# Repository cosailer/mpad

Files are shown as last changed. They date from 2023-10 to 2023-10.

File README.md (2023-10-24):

# mpad
**>> info**\
a 12 key macropad designed with atmega32u4, compatible with QMK, which is built with **virtser** and **I2C** enabled. the virtual serial port is used to control the 12 onboard backlight led, the I2C bus has a gesture sensor APDS-9960 connected to detect hand movement direction(up/down/left/right/near/far), proximity and light intensity. there is also a mouse encoder mounted.

**>> files**\
**mpad** :KiCad design files\
**qmk_firmware\keyboards\mpad** : firmware source for qmk build system\
**mpad.py** : a python test script to control the backlight LED via serial port\
**register_dump.txt** : an example register dump for APDS-9960

**>> setup**\
1, pin assignment, left: key and matrix assignment, right: backlight pin assignment
```
        D5     D4     D6       0,F5
     ┌──────┬──────┬──────┐
  B4 │ ESC  │ CALC │ MYCM │    1,B2   2,B1   3,B0
     ├──────┼──────┼──────┤
  B5 │ Ctl+C│ DEL  │ BSPC │    4,B3   5,F6   6,E6
     ├──────┼──────┼──────┤
  B6 │ SPACE│  Up  │  ENT │    7,F7   8,D7   9,F4
     ├──────┼──────┼──────┤
  B7 │ Left │ Down │ Right│   10,C6  11,C7  12,E2
     └──────┴──────┴──────┘
```

2, the onboard gesture sensor APDS-9960 is installed horizontally, the down movement is mapped to left key, up => right key, left => up key, right => down key

3, the 12 key individual backlight(single color) can be controlled from PC or mcu directly, allows it to be a LED notification light

the communication protocol: (each [xx] corresponds to 1 byte)
```
cmd 1: [0xAA] [ B1 ] [ B2 ] [0xE1] : set back light   ACK 1:[0xE1] ['\n']
cmd 2: [0xAA] [0xE2] : request timer                  ACK 2:[0xE2] [ T1 ] [ T2 ] [ T3 ] [ T4 ] ['\n']
cmd 3: [0xAA] [0xE3] : request voltage                ACK 3:[0xE3] [ U1 ] [ U2 ] ['\n']
cmd 4: [0xAA] [0xE4] : request die_temp               ACK 4:[0xE4] [ D1 ] [ D2 ] ['\n']
cmd 5: [0xAA] [0xE5] : request proximity              ACK 5:[0xE5] [ P1 ] ['\n']
cmd 6: [0xAA] [0xE6] : request light                  ACK 6:[0xE6] [ L1 ] [ L2 ] ['\n']
```
the script **mpad.py** sends commands to mpad every 100ms, to control the backlight LED and request some other system information. 

4, an onboard mouse encoder is mapped to volume control, which can be controlled via one finger

**>> PCB**\
the PCB is designed with KiCad 7.07. with the addition of an encoder, the PCB height size has grown over the 100mm. a small daughter board is attached to mount the gesture sensor and the encoder, the daughter board also has some extra room to mount other I2C sensors.

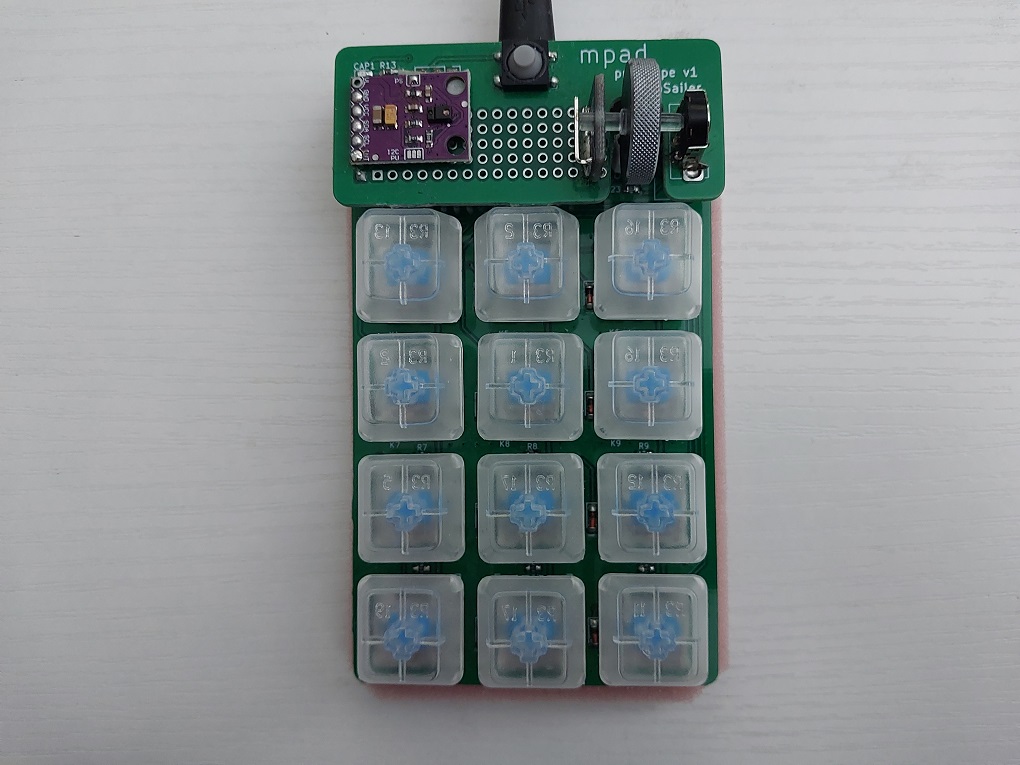
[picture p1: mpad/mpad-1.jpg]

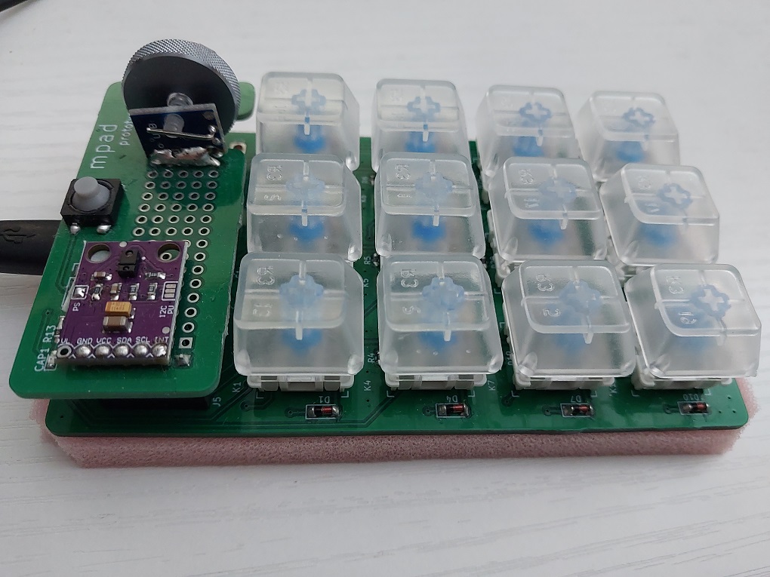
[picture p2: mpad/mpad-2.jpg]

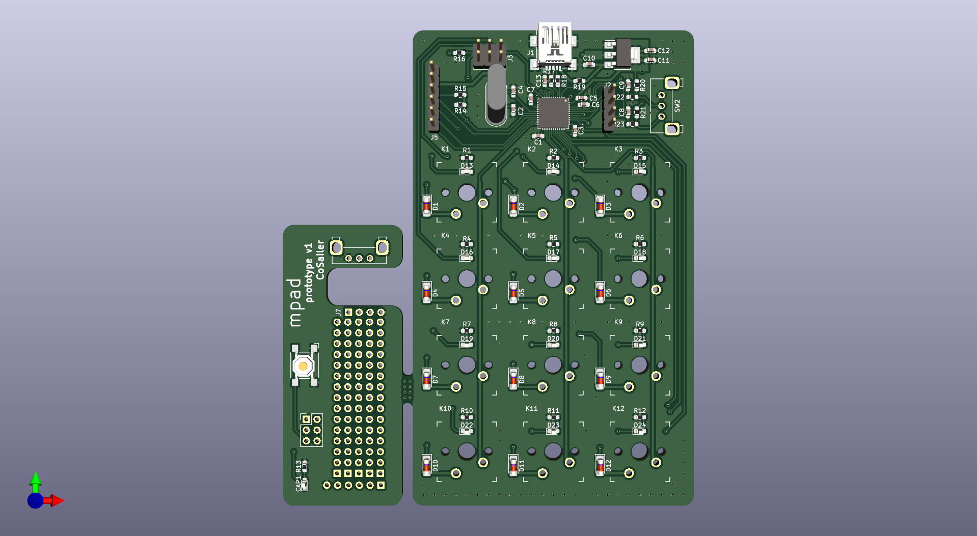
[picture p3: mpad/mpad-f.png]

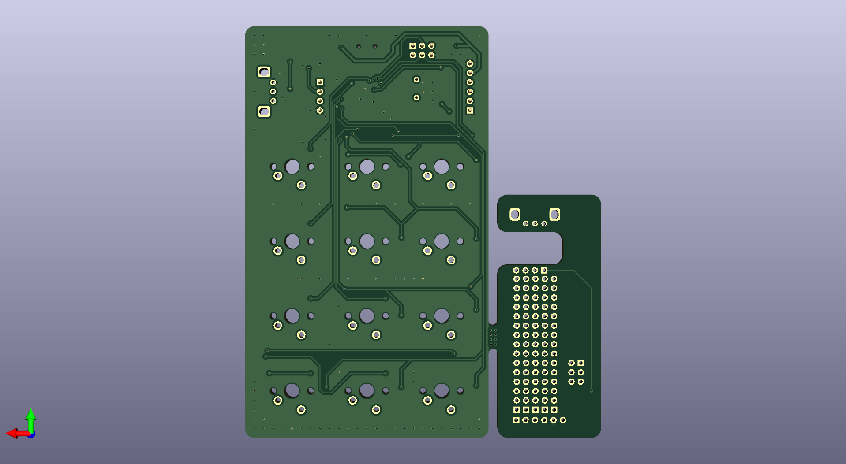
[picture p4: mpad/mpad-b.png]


**>> notes**\
1, even with interrupt enabled, the driver for the APDS-9960 still needs hundreds of milliseconds to measure/calculate the direction of the movements, during this time the keypad will not respond to other inputs, this is the limitation of the sensor.

2, apart from normal movement direction detection, another gesture is also possible: **proximity tap** within a predfined time window (e.g. 1.5 seconds), it could be one tap, two taps or more taps. but proximity tap cannot be enabled togethe with the normal gesture detection.

3, the APDS-9960 interrupt is active low.

4, the serial port in qmk running on atmega32u4 can only process the received data one byte a time, so that it does not block normal keyboard functions.

**>> refernces**\
1, https://qmk.fm \
2, https://github.com/njeff/cherryblossom \
3, https://www.broadcom.com/products/optical-sensors/integrated-ambient-light-and-proximity-sensors/apds-9960 \
4, https://learn.sparkfun.com/tutorials/apds-9960-rgb-and-gesture-sensor-hookup-guide/all

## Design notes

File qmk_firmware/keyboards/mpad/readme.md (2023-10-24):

# mpad

mpad

*A short description of the keyboard/project*

* Keyboard Maintainer: [CoSailer](https://github.com/CoSailer)
* Hardware Supported: *The PCBs, controllers supported*
* Hardware Availability: *Links to where you can find this hardware*

Make example for this keyboard (after setting up your build environment):

    make mpad:default

Flashing example for this keyboard:

    make mpad:default:flash

See the [build environment setup](https://docs.qmk.fm/#/getting_started_build_tools) and the [make instructions](https://docs.qmk.fm/#/getting_started_make_guide) for more information. Brand new to QMK? Start with our [Complete Newbs Guide](https://docs.qmk.fm/#/newbs).

## Bootloader

Enter the bootloader in 3 ways:

* **Bootmagic reset**: Hold down the key at (0,0) in the matrix (usually the top left key or Escape) and plug in the keyboard
* **Physical reset button**: Briefly press the button on the back of the PCB - some may have pads you must short instead
* **Keycode in layout**: Press the key mapped to `RESET` if it is available

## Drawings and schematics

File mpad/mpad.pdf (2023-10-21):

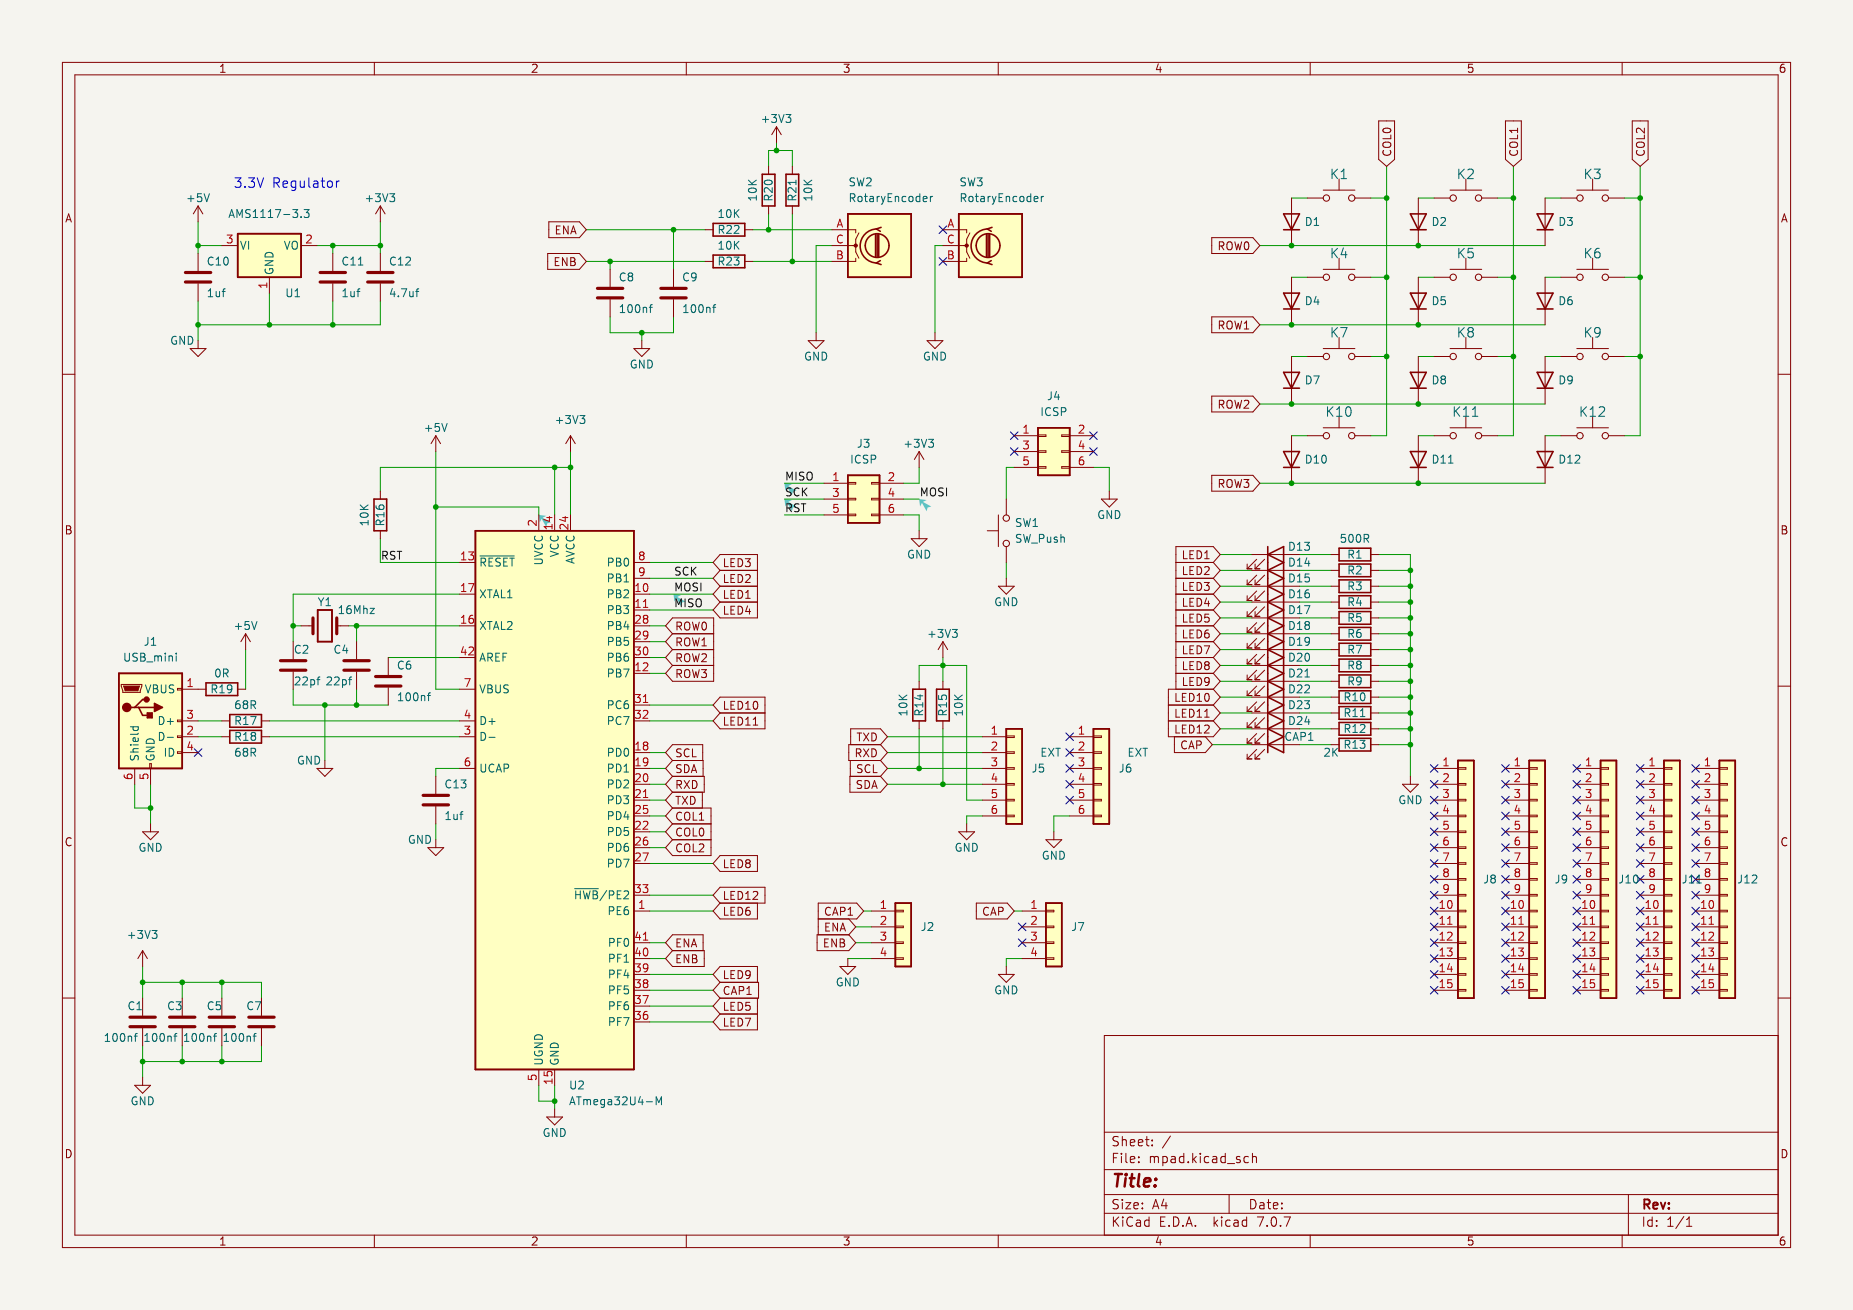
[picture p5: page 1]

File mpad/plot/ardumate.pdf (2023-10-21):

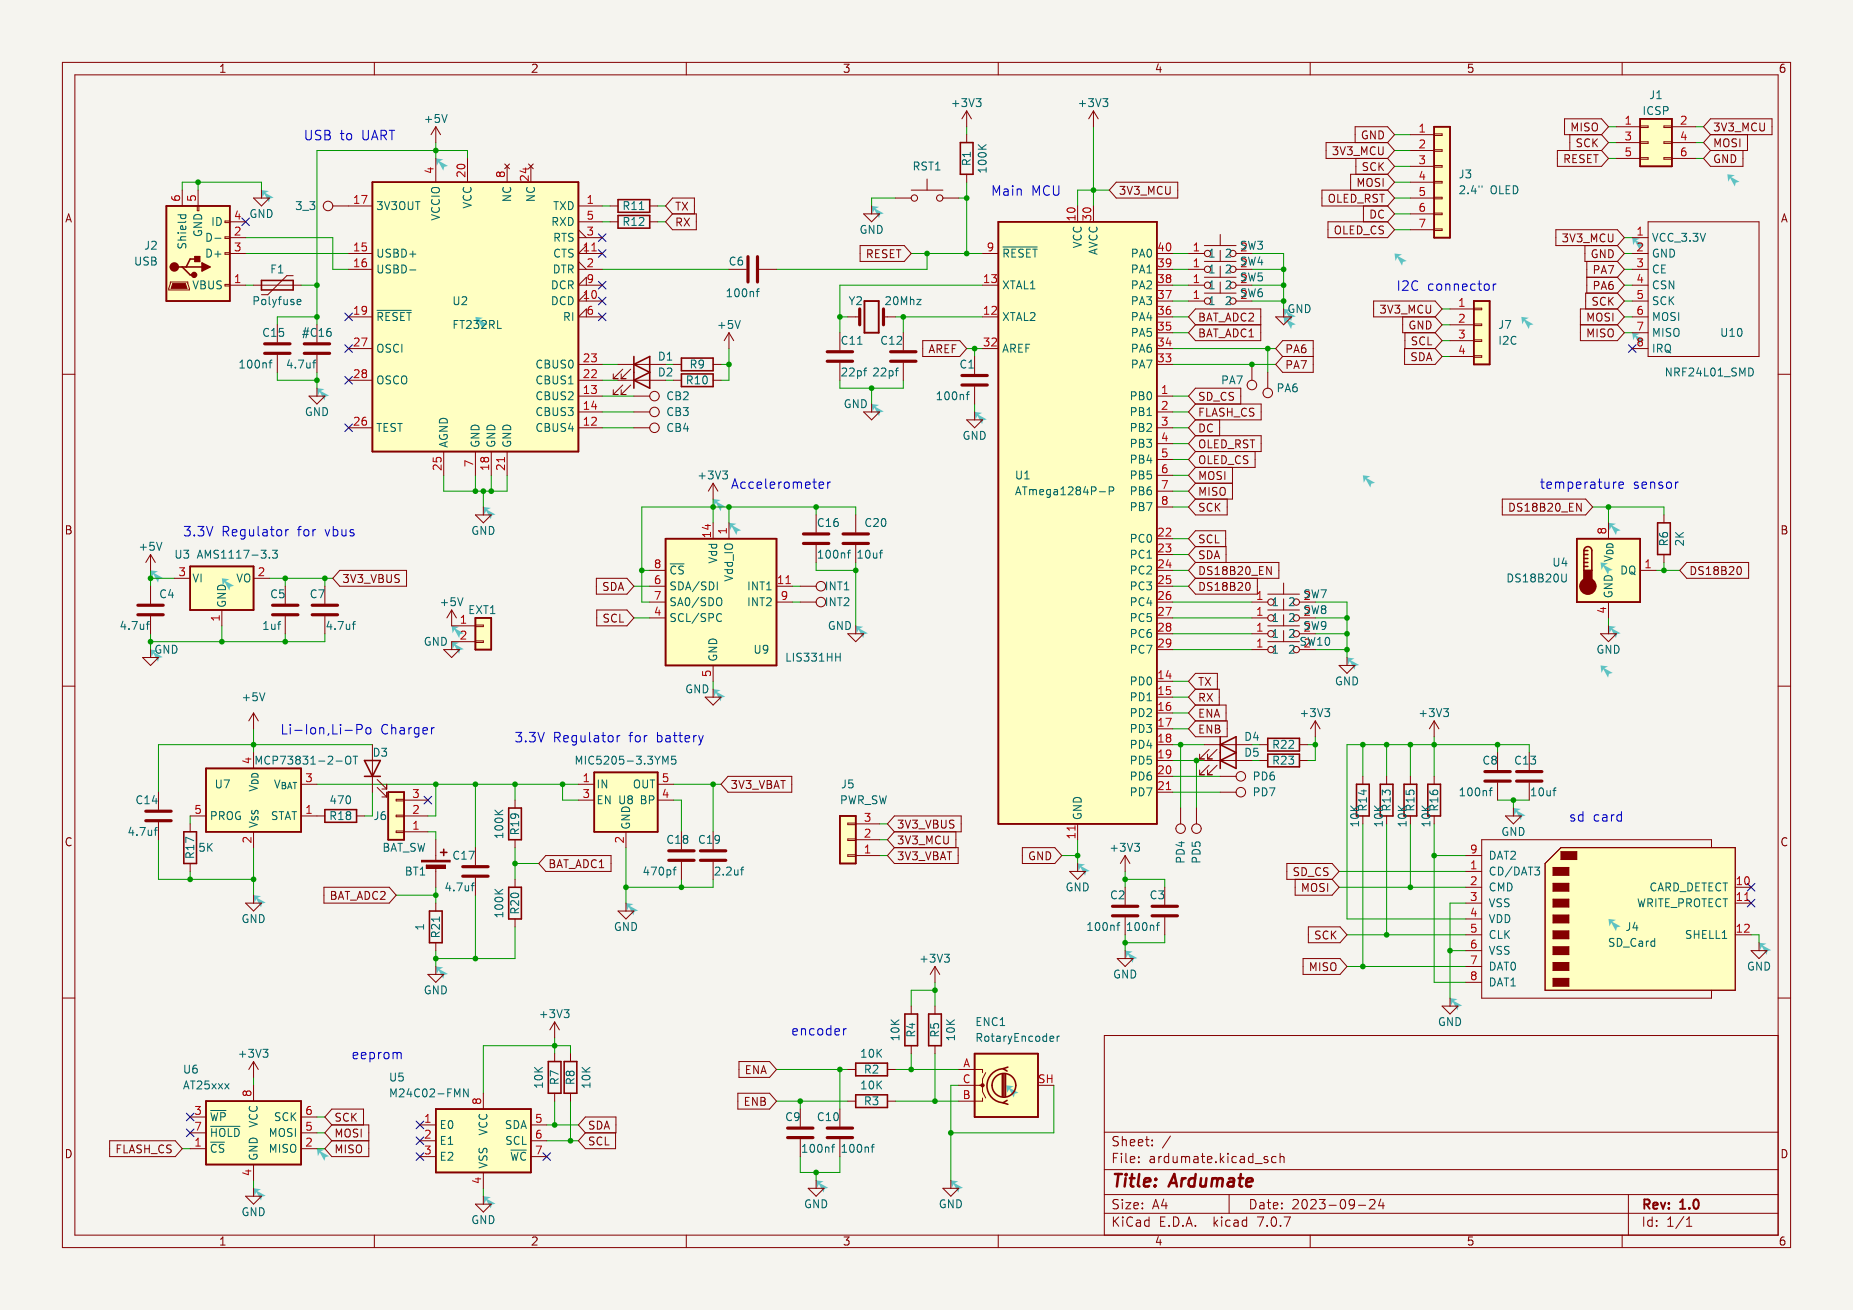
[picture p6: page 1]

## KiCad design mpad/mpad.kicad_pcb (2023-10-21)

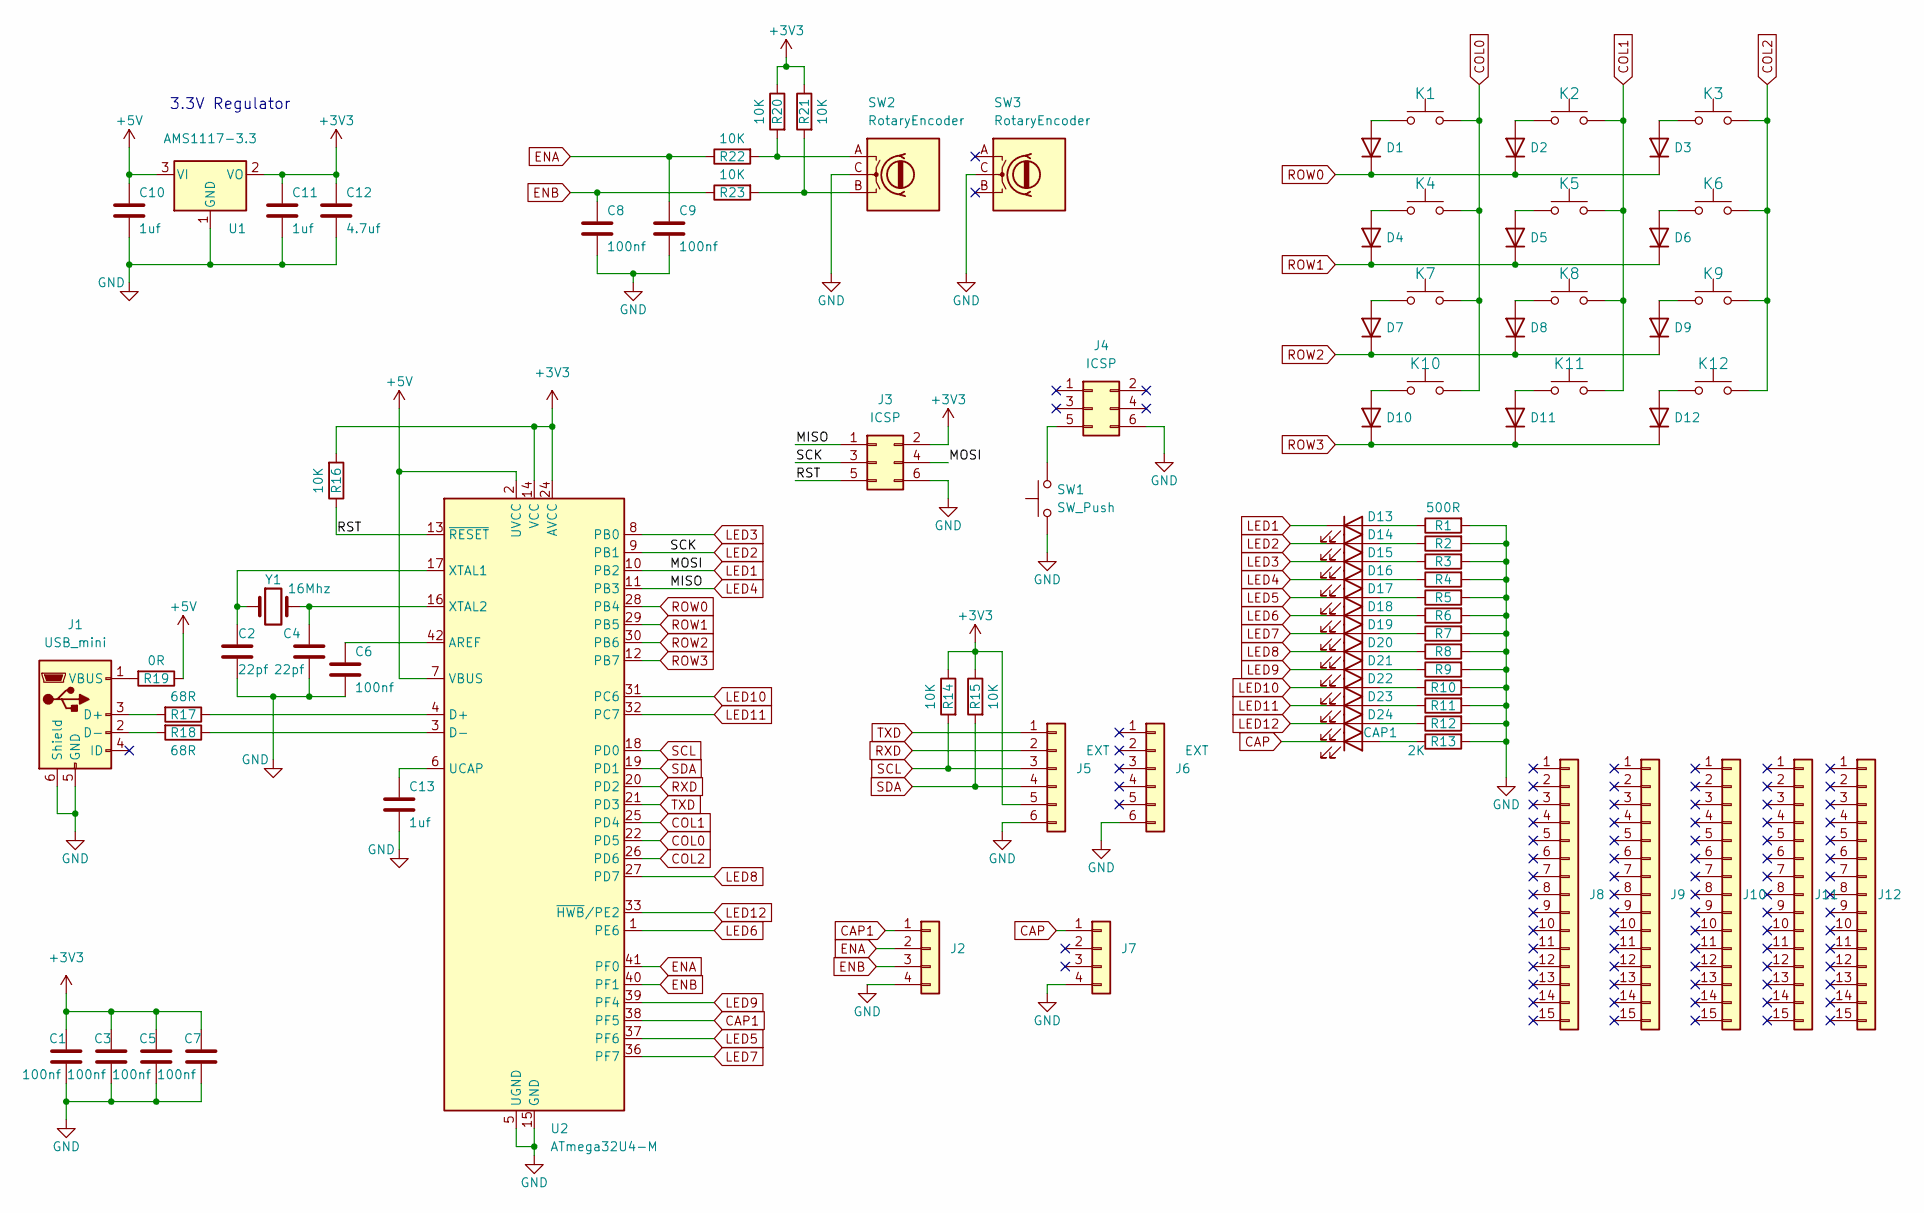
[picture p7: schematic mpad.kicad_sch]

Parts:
C1, C3, C5, C6, C7, C8, C9: 100nf; C_0603_1608Metric_Pad1.08x0.95mm_HandSolder
C2, C4: 22pf; C_0603_1608Metric_Pad1.08x0.95mm_HandSolder
C10, C11, C13: 1uf; C_0603_1608Metric_Pad1.08x0.95mm_HandSolder
C12: 4.7uf; C_0603_1608Metric_Pad1.08x0.95mm_HandSolder
CAP1: LED; LED_0603_1608Metric_Pad1.05x0.95mm_HandSolder
D1, D2, D3, D4, D5, D6, D7, D8, D9, D10, D11, D12: D; D_MiniMELF
D13, D14, D15, D16, D17, D18, D19, D20, D21, D22, D23, D24: LED; LED_0603_1608Metric_Pad1.05x0.95mm_HandSolder
J1: USB_mini; USB_Mini-B_Wuerth_65100516121_Horizontal
J2, J7: Status; PinHeader_1x04_P2.54mm_Vertical
J3, J4: ICSP; PinHeader_2x03_P2.54mm_Vertical
J5, J6: EXT; PinHeader_1x06_P2.54mm_Vertical
J8, J9, J10, J11, J12: UART; PinHeader_1x15_P2.54mm_Vertical
K1, K2, K3, K4, K5, K6, K7, K8, K9, K10, K11, K12: KEYSW; SW_MX
R1, R2, R3, R4, R5, R6, R7, R8, R9, R10, R11, R12: 500R; R_0603_1608Metric_Pad0.98x0.95mm_HandSolder
R13: 2K; R_0603_1608Metric_Pad0.98x0.95mm_HandSolder
R14, R15, R16, R20, R21, R22, R23: 10K; R_0603_1608Metric_Pad0.98x0.95mm_HandSolder
R17, R18: 68R; R_0603_1608Metric_Pad0.98x0.95mm_HandSolder
R19: 0R; R_0603_1608Metric_Pad0.98x0.95mm_HandSolder
SW1: SW_Push; SW_SPST_Omron_B3FS-100xP
SW2, SW3: RotaryEncoder; RotaryEncoder_Bourns_Horizontal_PEC12R-2xxxF-Nxxxx
U1: AMS1117-3.3; SOT-223-3_TabPin2
U2: ATmega32U4-M; QFN-44-1EP_7x7mm_P0.5mm_EP5.15x5.15mm_no_pad
Y1: 16Mhz; Crystal_HC18-U_Vertical

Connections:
+3V3: C1.1, C3.1, C5.1, C7.1, C11.1, C12.1, J3.2, J5.5, R14.1, R15.1, R16.2, R20.1, R21.1, U1.2 (VO), U2.14 (VCC), U2.24 (AVCC), U2.34 (VCC), U2.44 (AVCC)
+5V: C10.1, R19.1, U1.3 (VI), U2.2 (UVCC), U2.7 (VBUS)
/RST: J3.5, R16.1, U2.13 (~RESET)
CAP: CAP1.1 (K), J7.1
CAP1: J2.1, U2.38 (PF5)
COL0: K1.2, K4.2, K7.2, K10.2, U2.22 (PD5)
COL1: K2.2, K5.2, K8.2, K11.2, U2.25 (PD4)
COL2: K3.2, K6.2, K9.2, K12.2, U2.26 (PD6)
ENA: C9.1, J2.2, R22.1, U2.41 (PF0)
ENB: C8.1, J2.3, R23.1, U2.40 (PF1)
GND: C1.2, C2.2, C3.2, C4.2, C5.2, C6.2, C7.2, C8.2, C9.2, C10.2, C11.2, C12.2, C13.2, J1.5 (GND), J1.6 (Shield), J2.4, J3.6, J4.6, J5.6, J6.6, J7.4, R1.2, R2.2, R3.2, R4.2, R5.2, R6.2, R7.2, R8.2, R9.2, R10.2, R11.2, R12.2, R13.2, SW1.1, SW2.C, SW3.C, U1.1 (GND), U2.5 (UGND), U2.15 (GND), U2.23 (GND), U2.35 (GND), U2.43 (GND)
LED1: D13.1 (K), J3.4, U2.10 (PB2)
LED2: D14.1 (K), J3.3, U2.9 (PB1)
LED3: D15.1 (K), U2.8 (PB0)
LED4: D16.1 (K), J3.1, U2.11 (PB3)
LED5: D17.1 (K), U2.37 (PF6)
LED6: D18.1 (K), U2.1 (PE6)
LED7: D19.1 (K), U2.36 (PF7)
LED8: D20.1 (K), U2.27 (PD7)
LED9: D21.1 (K), U2.39 (PF4)
LED10: D22.1 (K), U2.31 (PC6)
LED11: D23.1 (K), U2.32 (PC7)
LED12: D24.1 (K), U2.33 (~HWB/PE2)
unnamed: CAP1.2 (A), R13.1
unnamed: D1.2 (A), K1.1
unnamed: D2.2 (A), K2.1
unnamed: D3.2 (A), K3.1
unnamed: D4.2 (A), K4.1
unnamed: D5.2 (A), K5.1
unnamed: D6.2 (A), K6.1
unnamed: D7.2 (A), K7.1
unnamed: D8.2 (A), K8.1
unnamed: D9.2 (A), K9.1
unnamed: D10.2 (A), K10.1
unnamed: D11.2 (A), K11.1
unnamed: D12.2 (A), K12.1
unnamed: D13.2 (A), R1.1
unnamed: D14.2 (A), R2.1
unnamed: D15.2 (A), R3.1
unnamed: D16.2 (A), R4.1
unnamed: D17.2 (A), R5.1
unnamed: D18.2 (A), R6.1
unnamed: D19.2 (A), R7.1
unnamed: D20.2 (A), R8.1
unnamed: D21.2 (A), R9.1
unnamed: D22.2 (A), R10.1
unnamed: D23.2 (A), R11.1
unnamed: D24.2 (A), R12.1
unnamed: J1.3 (D+), R17.2
unnamed: J1.2 (D-), R18.2
unnamed: J1.1 (VBUS), R19.2
unnamed: J4.5, SW1.2
unnamed: R20.2, R22.2, SW2.A
unnamed: R21.2, R23.2, SW2.B
unnamed: C6.1, U2.42 (AREF)
unnamed: R17.1, U2.4 (D+)
unnamed: R18.1, U2.3 (D-)
unnamed: C13.1, U2.6 (UCAP)
unnamed: C2.1, U2.17 (XTAL1), Y1.1
unnamed: C4.1, U2.16 (XTAL2), Y1.2
ROW0: D1.1 (K), D2.1 (K), D3.1 (K), U2.28 (PB4)
ROW1: D4.1 (K), D5.1 (K), D6.1 (K), U2.29 (PB5)
ROW2: D7.1 (K), D8.1 (K), D9.1 (K), U2.30 (PB6)
ROW3: D10.1 (K), D11.1 (K), D12.1 (K), U2.12 (PB7)
RXD: J5.2, U2.20 (PD2)
SCL: J5.3, R14.2, U2.18 (PD0)
SDA: J5.4, R15.2, U2.19 (PD1)
TXD: J5.1, U2.21 (PD3)

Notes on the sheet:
3.3V Regulator

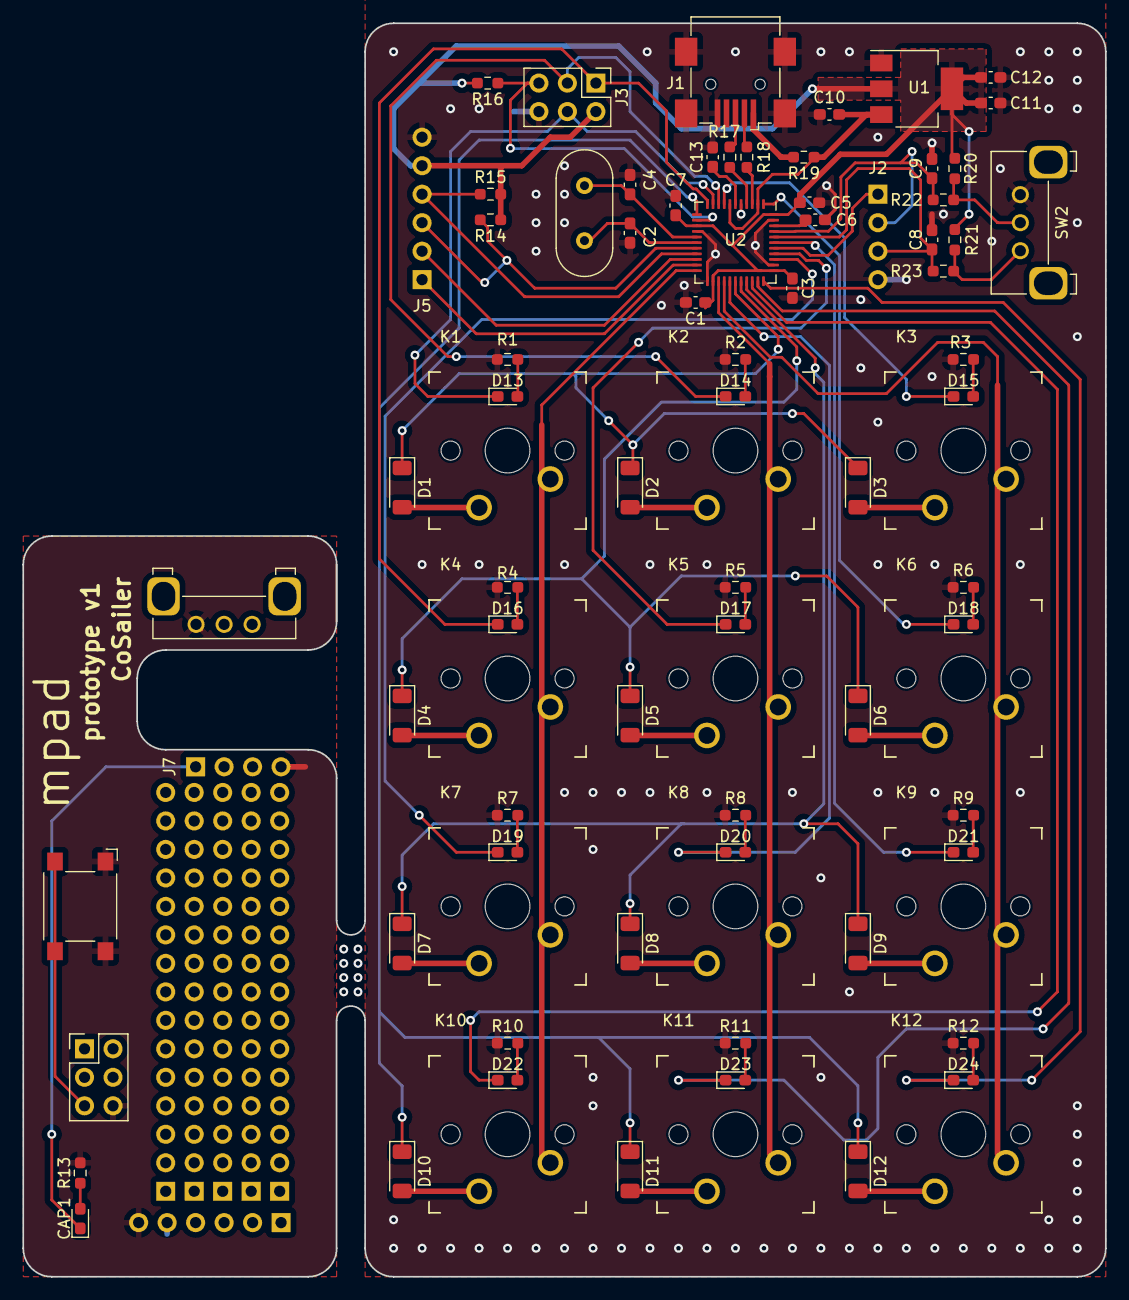
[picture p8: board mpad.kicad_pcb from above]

Board: 2 copper layers, 96.5 x 111.8 mm, 91 parts (0 on the bottom side), 68 nets.

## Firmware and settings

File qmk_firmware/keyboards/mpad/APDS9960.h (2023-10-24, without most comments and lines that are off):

#include "stdint.h"
#define SparkFun_APDS9960_H
#define TIMEOUT                 5
#define APDS9960_I2C_ADDR       (0x39 << 1)
#define GESTURE_THRESHOLD_OUT   10
#define GESTURE_SENSITIVITY_1   50
#define GESTURE_SENSITIVITY_2   20
#define ERROR                   0xFF
#define APDS9960_ID_1           0xAB
#define APDS9960_ID_2           0x9C
#define FIFO_PAUSE_TIME         30      // Wait period (ms) between FIFO reads
#define APDS9960_ENABLE         0x80
#define APDS9960_ATIME          0x81
#define APDS9960_WTIME          0x83
#define APDS9960_AILTL          0x84
#define APDS9960_AILTH          0x85
#define APDS9960_AIHTL          0x86
#define APDS9960_AIHTH          0x87
#define APDS9960_PILT           0x89
#define APDS9960_PIHT           0x8B
#define APDS9960_PERS           0x8C
#define APDS9960_CONFIG1        0x8D
#define APDS9960_PPULSE         0x8E
#define APDS9960_CONTROL        0x8F
#define APDS9960_CONFIG2        0x90
#define APDS9960_ID             0x92
#define APDS9960_STATUS         0x93
#define APDS9960_CDATAL         0x94
#define APDS9960_CDATAH         0x95
#define APDS9960_RDATAL         0x96
#define APDS9960_RDATAH         0x97
#define APDS9960_GDATAL         0x98
#define APDS9960_GDATAH         0x99
#define APDS9960_BDATAL         0x9A
#define APDS9960_BDATAH         0x9B
#define APDS9960_PDATA          0x9C
#define APDS9960_POFFSET_UR     0x9D
#define APDS9960_POFFSET_DL     0x9E
#define APDS9960_CONFIG3        0x9F
#define APDS9960_GPENTH         0xA0
#define APDS9960_GEXTH          0xA1
#define APDS9960_GCONF1         0xA2
#define APDS9960_GCONF2         0xA3
#define APDS9960_GOFFSET_U      0xA4
#define APDS9960_GOFFSET_D      0xA5
#define APDS9960_GOFFSET_L      0xA7
#define APDS9960_GOFFSET_R      0xA9
#define APDS9960_GPULSE         0xA6
#define APDS9960_GCONF3         0xAA
#define APDS9960_GCONF4         0xAB
#define APDS9960_GFLVL          0xAE
#define APDS9960_GSTATUS        0xAF
#define APDS9960_IFORCE         0xE4
#define APDS9960_PICLEAR        0xE5
#define APDS9960_CICLEAR        0xE6
#define APDS9960_AICLEAR        0xE7
#define APDS9960_GFIFO_U        0xFC
#define APDS9960_GFIFO_D        0xFD
#define APDS9960_GFIFO_L        0xFE
#define APDS9960_GFIFO_R        0xFF
#define APDS9960_PON            0b00000001
#define APDS9960_AEN            0b00000010
#define APDS9960_PEN            0b00000100
#define APDS9960_WEN            0b00001000
#define APSD9960_AIEN           0b00010000
#define APDS9960_PIEN           0b00100000
#define APDS9960_GEN            0b01000000
#define APDS9960_GVALID         0b00000001
#define SET_MODE_OFF            0
#define SET_MODE_ON             1
#define POWER                   0
#define AMBIENT_LIGHT           1
#define PROXIMITY               2
#define SET_MODE_WAIT           3
#define AMBIENT_LIGHT_INT       4
#define PROXIMITY_INT           5
#define GESTURE                 6
#define ALL                     7
#define LED_DRIVE_100MA         0
#define LED_DRIVE_50MA          1
#define LED_DRIVE_25MA          2
#define LED_DRIVE_12_5MA        3
#define PGAIN_1X                0
#define PGAIN_2X                1
#define PGAIN_4X                2
#define PGAIN_8X                3
#define AGAIN_1X                0
#define AGAIN_4X                1
#define AGAIN_16X               2
#define AGAIN_64X               3
#define GGAIN_1X                0
#define GGAIN_2X                1
#define GGAIN_4X                2
#define GGAIN_8X                3
#define LED_BOOST_100           0
#define LED_BOOST_150           1
#define LED_BOOST_200           2
#define LED_BOOST_300           3
#define GWTIME_0MS              0
#define GWTIME_2_8MS            1
#define GWTIME_5_6MS            2
#define GWTIME_8_4MS            3
#define GWTIME_14_0MS           4
#define GWTIME_22_4MS           5
#define GWTIME_30_8MS           6
#define GWTIME_39_2MS           7
#define DEFAULT_ATIME           219     // 103ms
#define DEFAULT_WTIME           246     // 27ms
#define DEFAULT_PROX_PPULSE     0x87    // 16us, 8 pulses
#define DEFAULT_GESTURE_PPULSE  0x89    // 16us, 10 pulses
#define DEFAULT_POFFSET_UR      0       // 0 offset
#define DEFAULT_POFFSET_DL      0       // 0 offset
#define DEFAULT_CONFIG1         0x60    // No 12x wait (WTIME) factor
#define DEFAULT_LDRIVE          LED_DRIVE_100MA
#define DEFAULT_PGAIN           PGAIN_1X
#define DEFAULT_AGAIN           AGAIN_1X
#define DEFAULT_PILT            0       // Low proximity threshold
#define DEFAULT_PIHT            50      // High proximity threshold
#define DEFAULT_AILT            0xFFFF  // Force interrupt for calibration
#define DEFAULT_AIHT            0
#define DEFAULT_PERS            0x11    // 2 consecutive prox or ALS for int.
#define DEFAULT_CONFIG2         0x01    // No saturation interrupts or LED boost
#define DEFAULT_CONFIG3         0       // Enable all photodiodes, no SAI
#define DEFAULT_GPENTH          30      // Threshold for entering gesture mode
#define DEFAULT_GEXTH           15      // Threshold for exiting gesture mode
#define DEFAULT_GCONF1          0x40    // 4 gesture events for int., 1 for exit
#define DEFAULT_GGAIN           GGAIN_1X //GGAIN_1X
#define DEFAULT_GLDRIVE         LED_DRIVE_100MA
#define DEFAULT_GWTIME          GWTIME_2_8MS
#define DEFAULT_GOFFSET         0       // No offset scaling for gesture mode
#define DEFAULT_GPULSE          0xC9    // 32us, 10 pulses
#define DEFAULT_GCONF3          0       // All photodiodes active during gesture
#define DEFAULT_GIEN            0       // Disable gesture interrupts
enum {
  DIR_NONE,
  DIR_LEFT,
  DIR_RIGHT,
  DIR_UP,
  DIR_DOWN,
  DIR_NEAR,
  DIR_FAR,
  DIR_ALL
};
enum {
  NA_STATE,
  NEAR_STATE,
  FAR_STATE,
  ALL_STATE
};
typedef struct gesture_data_type {
    uint8_t u_data[32];
    uint8_t d_data[32];
    uint8_t l_data[32];
    uint8_t r_data[32];
    uint8_t index;
    uint8_t total_gestures;
    uint8_t in_threshold;
    uint8_t out_threshold;
} gesture_data_type;
uint8_t apds9960_init(void);
uint8_t getMode(void);
uint8_t setMode(uint8_t mode, uint8_t enable);
uint8_t enablePower(void);
uint8_t disablePower(void);
uint8_t enableLightSensor(uint8_t interrupts);
uint8_t disableLightSensor(void);
uint8_t enableProximitySensor(uint8_t interrupts);
uint8_t disableProximitySensor(void);
uint8_t enableGestureSensor(uint8_t interrupts);
uint8_t disableGestureSensor(void);
uint8_t getLEDDrive(void);
uint8_t setLEDDrive(uint8_t drive);
uint8_t getGestureLEDDrive(void);
uint8_t setGestureLEDDrive(uint8_t drive);
uint8_t getAmbientLightGain(void);
uint8_t setAmbientLightGain(uint8_t gain);
uint8_t getProximityGain(void);
uint8_t setProximityGain(uint8_t gain);
uint8_t getGestureGain(void);
uint8_t setGestureGain(uint8_t gain);
uint8_t getLightIntLowThreshold(uint16_t *threshold);
uint8_t setLightIntLowThreshold(uint16_t threshold);
uint8_t getLightIntHighThreshold(uint16_t *threshold);
uint8_t setLightIntHighThreshold(uint16_t threshold);
uint8_t getProximityIntLowThreshold(uint8_t *threshold);
uint8_t setProximityIntLowThreshold(uint8_t threshold);
uint8_t getProximityIntHighThreshold(uint8_t *threshold);
uint8_t setProximityIntHighThreshold(uint8_t threshold);
uint8_t getAmbientLightIntEnable(void);
uint8_t setAmbientLightIntEnable(uint8_t enable);
uint8_t getProximityIntEnable(void);
uint8_t setProximityIntEnable(uint8_t enable);
uint8_t getGestureIntEnable(void);
uint8_t setGestureIntEnable(uint8_t enable);
uint8_t clearAmbientLightInt(void);
uint8_t clearProximityInt(void);
uint8_t readAmbientLight(uint16_t *val);
uint8_t readRedLight(uint16_t *val);
uint8_t readGreenLight(uint16_t *val);
uint8_t readBlueLight(uint16_t *val);
uint8_t readProximity(uint8_t *val);
uint8_t isGestureAvailable(void);
int readGesture(void);
uint8_t wireWriteByte(uint8_t val);
uint8_t wireWriteDataByte(uint8_t reg, uint8_t val);
uint8_t wireWriteDataBlock(uint8_t reg, uint8_t *val, unsigned int len);
uint8_t wireReadDataByte(uint8_t reg, uint8_t *val);
int wireReadDataBlock(uint8_t reg, uint8_t *val, unsigned int len);

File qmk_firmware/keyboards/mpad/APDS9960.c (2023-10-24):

/**
 * Adapted from the Sparkfun Library by njeff
 * https://jeffreyni.blogspot.com/search/label/Numpad
 *
 * @file    SparkFun_APDS-9960.cpp
 * @brief   Library for the SparkFun APDS-9960 breakout board
 * @author  Shawn Hymel (SparkFun Electronics)
 *
 * @copyright   This code is public domain but you buy me a beer if you use
 * this and we meet someday (Beerware license).
 *
 * This library interfaces the Avago APDS-9960 to Arduino over I2C. The library
 * relies on the Arduino Wire (I2C) library. to use the library, instantiate an
 * APDS9960 object, call init(), and call the appropriate functions.
 *
 * APDS-9960 current draw tests (default parameters):
 *   Off:                   1mA
 *   Waiting for gesture:   14mA
 *   Gesture in progress:   35mA
 */

#include <APDS9960.h>
#include "../../platforms/avr/drivers/i2c_master.h"   
#include "quantum.h"

static gesture_data_type gesture_data_;
static int gesture_ud_delta_ = 0;
static int gesture_lr_delta_ = 0;
static int gesture_ud_count_ = 0;
static int gesture_lr_count_ = 0;
static int gesture_near_count_ = 0;
static int gesture_far_count_ = 0;
static int gesture_state_ = 0;
static int gesture_motion_ = DIR_NONE;

/* Gesture processing */
void resetGestureParameters(void);
uint8_t processGestureData(void);
uint8_t decodeGesture(void);

/* Proximity Interrupt Threshold */
uint8_t getProxIntLowThresh(void);
uint8_t setProxIntLowThresh(uint8_t threshold);
uint8_t getProxIntHighThresh(void);
uint8_t setProxIntHighThresh(uint8_t threshold);

/* LED Boost Control */
uint8_t getLEDBoost(void);
uint8_t setLEDBoost(uint8_t boost);

/* Proximity photodiode select */
uint8_t getProxGainCompEnable(void);
uint8_t setProxGainCompEnable(uint8_t enable);
uint8_t getProxPhotoMask(void);
uint8_t setProxPhotoMask(uint8_t mask);

/* Gesture threshold control */
uint8_t getGestureEnterThresh(void);
uint8_t setGestureEnterThresh(uint8_t threshold);
uint8_t getGestureExitThresh(void);
uint8_t setGestureExitThresh(uint8_t threshold);

/* Gesture LED, gain, and time control */
uint8_t getGestureWaitTime(void);
uint8_t setGestureWaitTime(uint8_t time);

/* Gesture mode */
uint8_t getGestureMode(void);
uint8_t setGestureMode(uint8_t mode);

/* Raw I2C Commands 
uint8_t wireWriteByte(uint8_t val);
uint8_t wireWriteDataByte(uint8_t reg, uint8_t val);
uint8_t wireWriteDataBlock(uint8_t reg, uint8_t *val, unsigned int len);
uint8_t wireReadDataByte(uint8_t reg, uint8_t *val);
int wireReadDataBlock(uint8_t reg, uint8_t *val, unsigned int len);
*/

/*******************************************************************************
 * Raw I2C Reads and Writes
 ******************************************************************************/

/**
 * @brief Writes a single byte to the I2C device (no register)
 *
 * @param[in] val the 1-byte value to write to the I2C device
 * @return True if successful write operation. False otherwise.
 */
uint8_t wireWriteByte(uint8_t val)
{
    return i2c_transmit(APDS9960_I2C_ADDR, &val, 1, TIMEOUT) == I2C_STATUS_SUCCESS;
}

/**
 * @brief Writes a single byte to the I2C device and specified register
 *
 * @param[in] reg the register in the I2C device to write to
 * @param[in] val the 1-byte value to write to the I2C device
 * @return True if successful write operation. False otherwise.
 */
uint8_t wireWriteDataByte(uint8_t reg, uint8_t val)
{
    return i2c_writeReg(APDS9960_I2C_ADDR, reg, &val, 1, TIMEOUT) == I2C_STATUS_SUCCESS;
}

/**
 * @brief Writes a block (array) of bytes to the I2C device and register
 *
 * @param[in] reg the register in the I2C device to write to
 * @param[in] val pointer to the beginning of the data byte array
 * @param[in] len the length (in bytes) of the data to write
 * @return True if successful write operation. False otherwise.
 */
uint8_t wireWriteDataBlock(  uint8_t reg, 
                          uint8_t *val, 
                          unsigned int len)
{
    return i2c_writeReg(APDS9960_I2C_ADDR, reg, val, len, TIMEOUT) == I2C_STATUS_SUCCESS;
}

/**
 * @brief Reads a single byte from the I2C device and specified register
 *
 * @param[in] reg the register to read from
 * @param[out] the value returned from the register
 * @return True if successful read operation. False otherwise.
 */
uint8_t wireReadDataByte(uint8_t reg, uint8_t *val)
{
    
    /* Indicate which register we want to read from */
    return i2c_readReg(APDS9960_I2C_ADDR, reg, val, 1, TIMEOUT) == I2C_STATUS_SUCCESS;
}

/**
 * @brief Reads a block (array) of bytes from the I2C device and register
 *
 * @param[in] reg the register to read from
 * @param[out] val pointer to the beginning of the data
 * @param[in] len number of bytes to read
 * @return Number of bytes read. -1 on read error.
 */
int wireReadDataBlock(   uint8_t reg, 
                         uint8_t *val, 
                         unsigned int len)
{
    // kind of not correct but works here
    if (i2c_readReg(APDS9960_I2C_ADDR, reg, val, len, TIMEOUT) == I2C_STATUS_SUCCESS) {
        return len;
    } else {
        return 0;
    }
}


/**
 * DRIVER
 */
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

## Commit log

2023-10-21 add pcb files
    [mpad-B_Cu.gbl, mpad-B_Mask.gbs, mpad-B_Paste.gbp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]
2023-10-24 add qmk source
    [register_dump.txt]
